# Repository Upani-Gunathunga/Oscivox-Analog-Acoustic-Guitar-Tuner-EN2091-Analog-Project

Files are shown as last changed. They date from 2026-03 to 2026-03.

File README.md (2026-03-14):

# 🎸 Oscivox-Analog-Acoustic-Guitar-Tuner-EN2091-Analog-Project
The Analog Acoustic Guitar Tuner is a fully analog signal-processing system that detects the frequency of a plucked guitar string and visually indicates whether the string is tuned correctly.  Unlike digital tuners, this device performs all signal processing using analog circuits, including filtering, frequency detection, and voltage comparison.

This repository presents the **Analog Acoustic Guitar Tuner** developed by **Team Oscivox** as part of the module:

IN23-S3-EN2091 – Laboratory Practice and Projects
Department of Electronic & Telecommunication Engineering
University of Moratuwa
---

# 📌 Project Overview

The **Analog Acoustic Guitar Tuner** is a **fully analog signal-processing system** that detects the frequency of a plucked guitar string and visually indicates whether the string is tuned correctly.

Unlike digital tuners, this device performs **all signal processing using analog circuits**, including filtering, frequency detection, and voltage comparison.

The system supports standard acoustic guitar tuning:

| String | Note | Frequency |
| --- | ---- | --- |
| 6 | E6 | 82.41 Hz  |
| 5 | A5 | 110 Hz |
| 4 | D4 | 146.83 Hz |
| 3 | G3 | 196 Hz |
| 2 | B2 | 246.94 Hz |
| 1 | E1 | 329.63 Hz |

The device operates using a **9V power supply** and provides tuning feedback using **LED indicators**.

---

# ⚙️ System Working Principle

The overall system processes the acoustic signal through several analog stages.

```
Guitar String Vibration
        ↓
Microphone Input
        ↓
Signal Amplification
        ↓
State Variable Bandpass Filter
        ↓
Schmitt Trigger
        ↓
Frequency-to-Voltage Converter
        ↓
Buffer Stage
        ↓
Comparator Circuit (Potential Dividers)
        ↓
LED Tuning Indicator
```

Each block performs a specific function in converting **sound → frequency → voltage → tuning indication**.

---

# 🔬 System Architecture

## 1️⃣ Microphone Input

🎤 **Purpose**

Convert acoustic vibrations of the guitar string into an electrical signal.

**Key components**

* Condenser microphone
* LM358 operational amplifier
* Variable resistor for gain adjustment

The microphone captures signals typically in the **60–400 Hz frequency range**.

---

## 2️⃣ Amplifier Stage

🔊 **Purpose**

Increase the microphone signal to a usable voltage level.

**Key component**

* **C1845 transistor amplifier**

The amplifier provides approximately:

* **Gain:** 35–40 dB
* **High input impedance (>1 MΩ)**

This stage ensures the signal is strong enough for further processing.

---

## 3️⃣ State Variable Filters

🎚 **Purpose**

Extract the **fundamental frequency** of the selected guitar note while suppressing harmonics and noise.

Six **second-order active band-pass filters** were designed, each corresponding to one guitar string frequency.

State variable filters were chosen because they:

* Provide **sharp frequency selectivity**
* Maintain signal amplitude better than passive filters
* Are suitable for **audio applications**

---

## 4️⃣ Schmitt Trigger

📉 **Purpose**

Convert the filtered analog waveform into a **clean digital square wave**.

**Key component**

* LM393 comparator

This stage removes noise and prepares the signal for frequency measurement.

---

## 5️⃣ Frequency-to-Voltage Converter

🔄 **Purpose**

Convert the signal frequency into a **proportional DC voltage**.

**Key component**

* **LM2917 Frequency-to-Voltage Converter**

This stage transforms frequency information into voltage that can be easily compared.

---

## 6️⃣ Buffer Stage

🧩 **Purpose**

Prevent loading between stages and stabilize the output signal.

**Key component**

* LM358 operational amplifier

---

## 7️⃣ Comparator and Output Indicator

💡 **Purpose**

Determine whether the detected frequency is:

* **Lower than the correct frequency**
* **Higher than the correct frequency**
* **Equal to the correct frequency**
  
Here, potential divider circuit is used to generate reference voltages corresponding to correct tuning frequency of the note as follows.

| Voltage (V) | Frequency (Hz) | Guitar Note |
| --- | --- | --- |
| 1.2 V | 82.4 Hz | E (Low E) |
| 1.6 V | 110 Hz | A |
| 2.1 V | 146.6 Hz | D |
| 2.8 V | 196 Hz | G |
| 3.5 V | 246.9 Hz | B |
| 4.6 V | 329.6 Hz | E (High E)  |

**Key component**

* LM393 comparator

**LED Indications**

| Condition | LED Output |
| --- | --- |
| Frequency too low  | 🟢 Green LED |
| Frequency too high | 🔴 Red LED |
| Correct tuning | 🟢🔴 Both LEDs |

The **output indication of comparator stage were designed as part of my circuit design contribution.**

---

# 🧩 PCB Design

The system was implemented on a **custom PCB designed in Altium**.

### Design considerations

* Efficient component placement
* Reduced noise coupling
* Clear signal routing for analog stages
* Stable power distribution
  
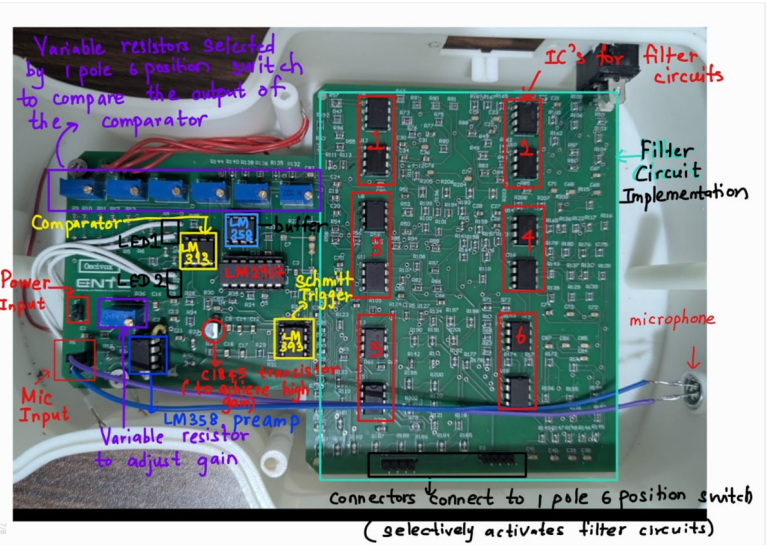
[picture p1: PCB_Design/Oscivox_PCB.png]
Oscivox PCB
  

---

# 🧱 Enclosure Design

The device enclosure was designed using **Autodesk Fusion**.

### Key design goals

* Compact handheld structure
* Easy access to the tuning dial
* Proper positioning of the **microphone near guitar strings**
* Protection of internal circuitry
  
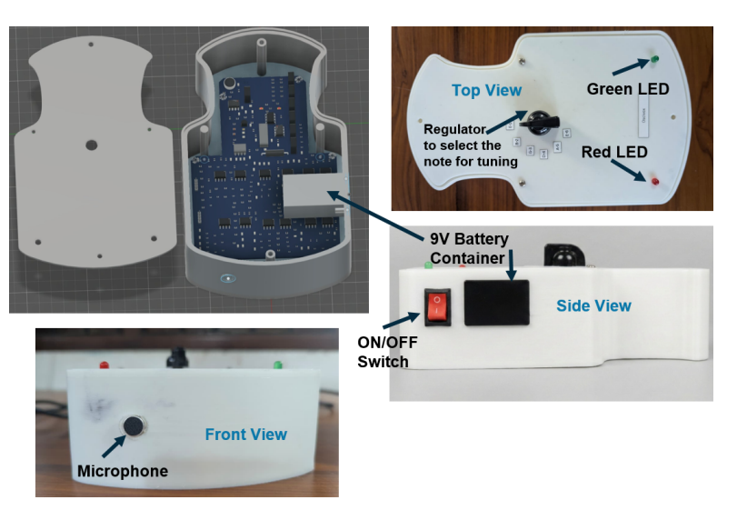
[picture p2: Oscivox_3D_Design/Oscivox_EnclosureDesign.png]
Oscivox Enclosure Design


---

# 🎥 Project Demonstration

A demonstration of the working tuner can be viewed below:

👉 **[Project Demo Video](ADD_VIDEO_LINK_HERE)**

---

# 👥 Team Oscivox

| Name | Index |
| --- | --- |
| Gunathunga U.A. | 230218G |
| Palihena H.H. | 230458P |
| Abeywardhana T.C.W. | 230012U |
| Perera K.W.A.O.V. | 230481E |

---

## 👥 Team Contributions

### **Gunathunga U.A. — 230218G**

* PCB schematic and layout design using **Altium**
* Circuit design for **comparator-based output indication**
* Breadboard testing, PCB debugging, and system assembly

### **Palihena H.H. — 230458P**

* **State Variable Filter** design and LTspice simulations
* Initial passive filter design exploration
* Breadboard implementation and functional testing

### **Abeywardhana T.C.W. — 230012U**

* **Microphone input circuit** and analog amplifier design
* **3D enclosure design** using Fusion
* PCB soldering and hardware assembly

### **Perera K.W.A.O.V. — 230481E**

* Circuit design for **Schmitt Trigger**, **Frequency-to-Voltage Converter**, and **Buffer**
* Design of **reference voltage potential dividers**
* Initial enclosure concept sketch
* Breadboard testing 

---

✔ **Repository Contents**

```
/PCB
/Schematics
/Enclosure
/Simulations
/Datasheet
/Final_Report
README.md
```

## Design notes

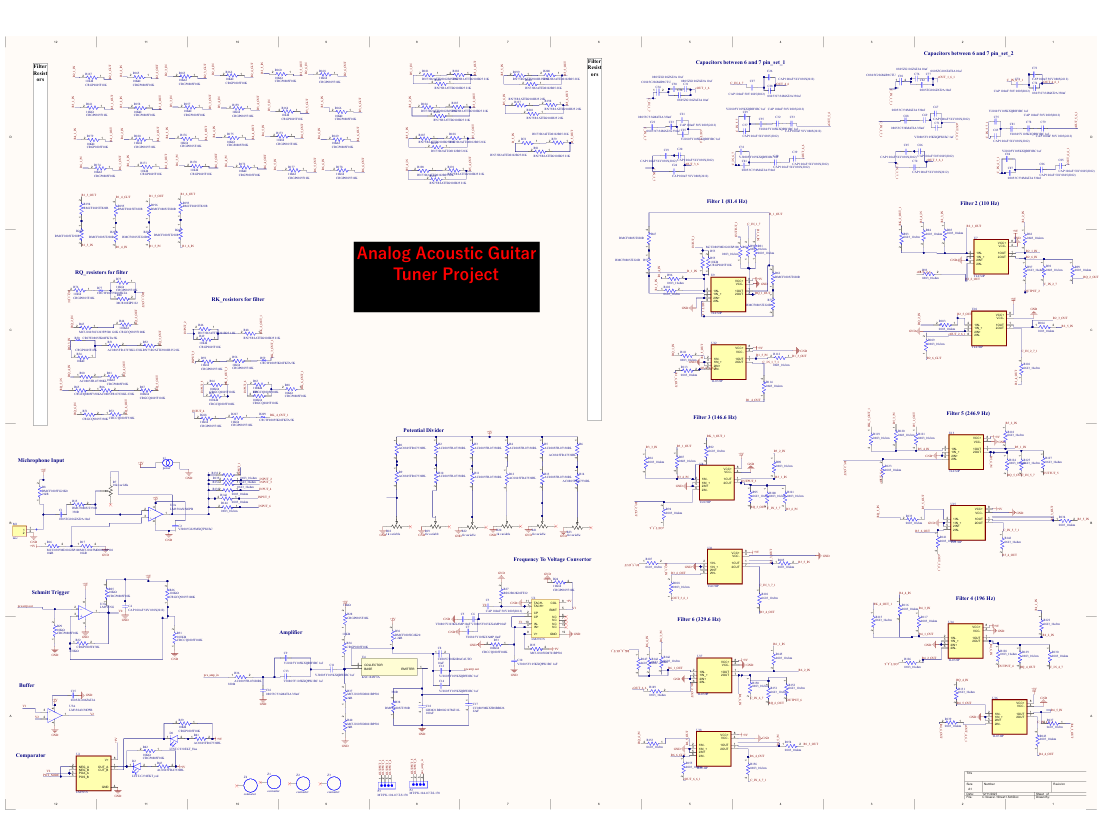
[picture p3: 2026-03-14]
PCB_Design/Oscivox_schematic.png

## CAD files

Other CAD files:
Oscivox_3D_Design/MainBody.f3z

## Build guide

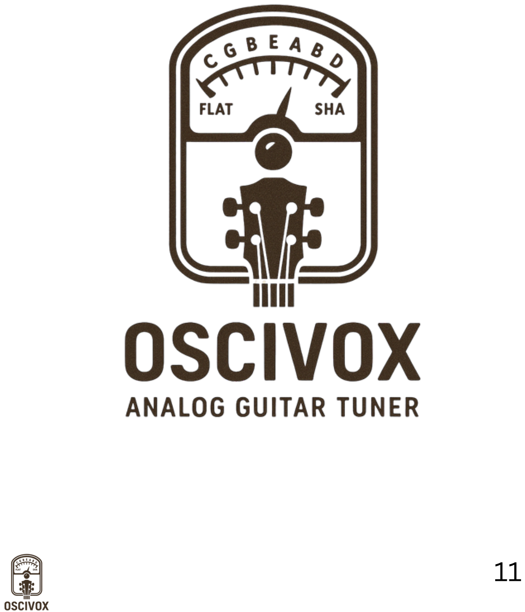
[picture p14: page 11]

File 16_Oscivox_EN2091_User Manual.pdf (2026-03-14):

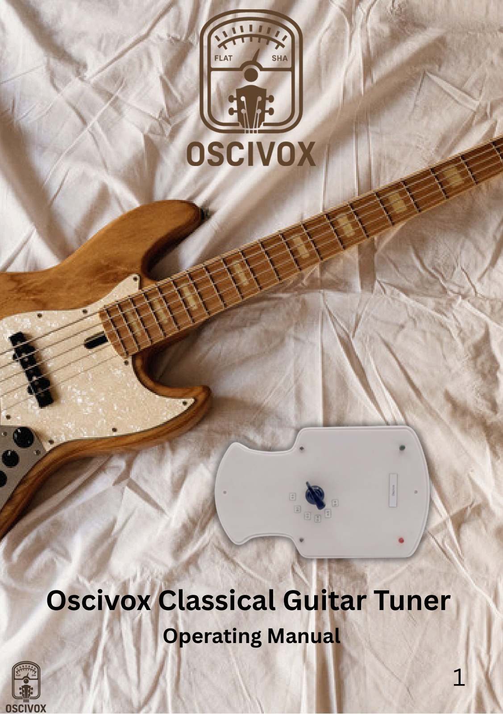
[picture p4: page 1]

# Oscivox Classical Guitar Tuner

## Operating Manual

## Content

## 1.Introduction 2.Safety Information 3.Product Overview 4.What’s in the box 5.Operating Instructions 6.Warranty Information 7.Technical Support and Warranty Claims

# Introduction

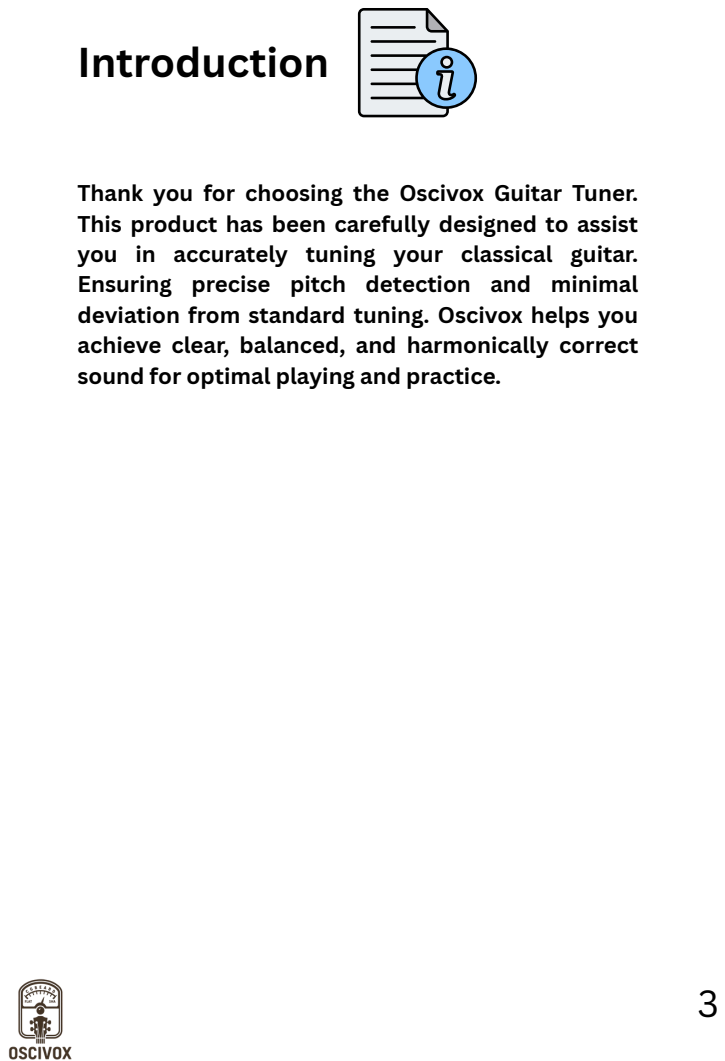
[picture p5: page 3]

Thank you for choosing the Oscivox Guitar Tuner.
This product has been carefully designed to assist
you in accurately tuning your classical guitar.
Ensuring precise pitch detection and minimal
deviation from standard tuning. Oscivox helps you
achieve clear, balanced, and harmonically correct
sound for optimal playing and practice.

Do not leave the device powered on for a long time, as this may damage the internal components.
Do not expose the device to moisture, rain, liquids, or direct heat sources.
Use only a 9 V dry cell battery with a maximum current rating of 300 mA.
Do not open or attempt to modify the device enclosure.
Avoid damaging or obstructing the built-in microphone, as this may affect tuning accuracy.

# Safety Information

# Product Overview

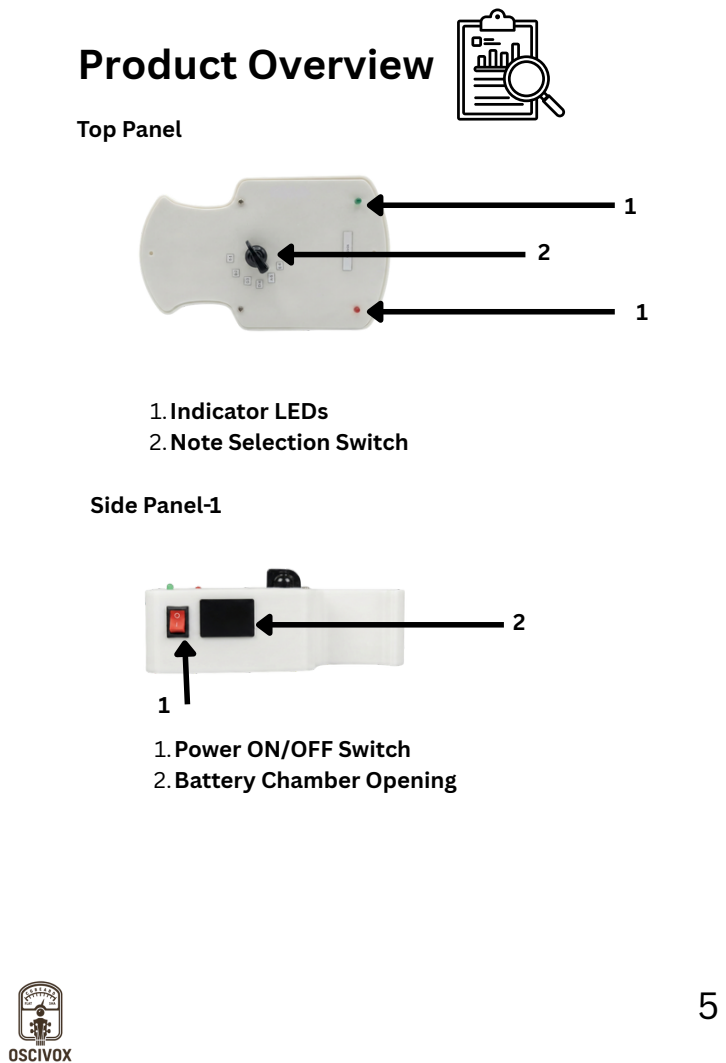
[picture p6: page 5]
Top Panel; Side Panel-1

1.Indicator LEDs
2.Note Selection Switch

1.Power ON/OFF Switch
2.Battery Chamber Opening

# Product Overview

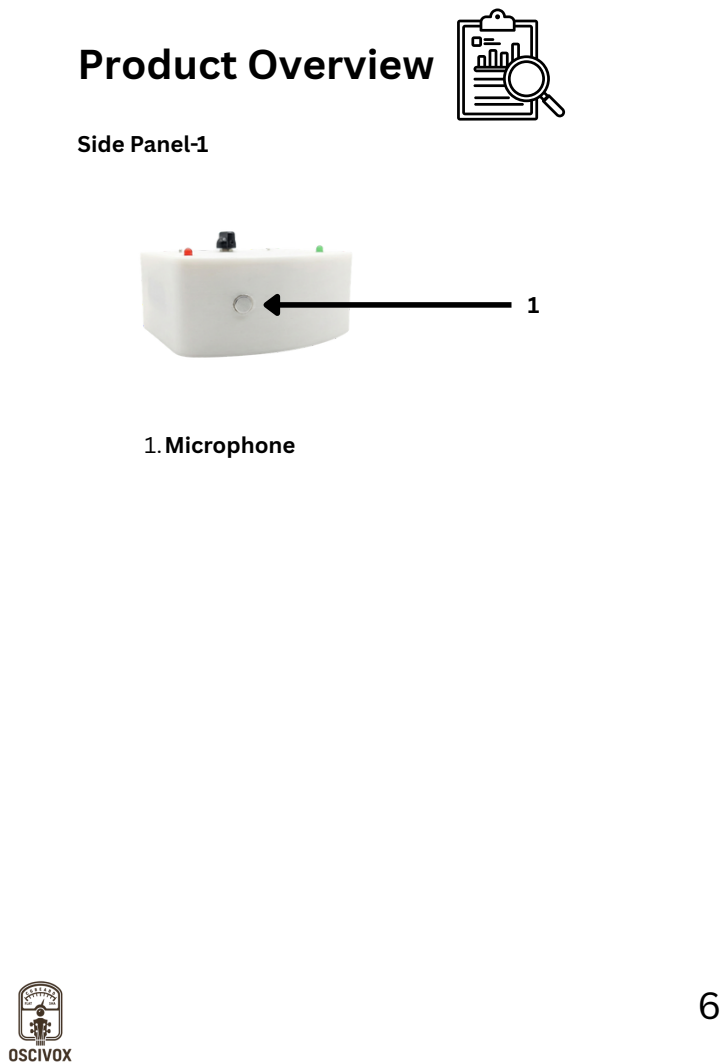
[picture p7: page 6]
Side Panel-1; 1.Microphone

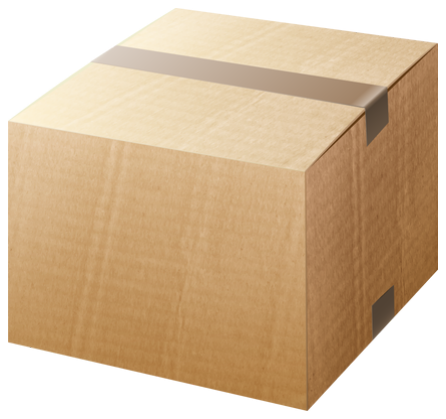
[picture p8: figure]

# What’s in the box

Box Content

Oscivox Guitar tuner unit
9V rechargeable batter
User Manual

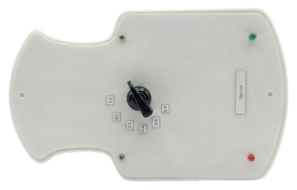
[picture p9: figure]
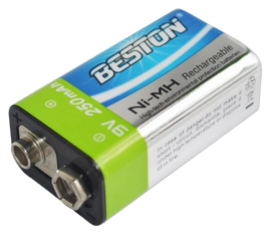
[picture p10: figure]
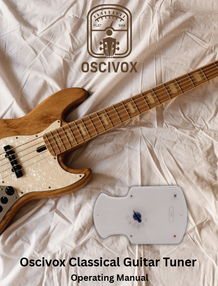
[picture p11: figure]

# Operating Instructions

1.Switch on the Oscivox Guitar Tuner. The green LED will illuminate to indicate that the device is powered on.
2.Allow the device to warm up for 30 to 60 seconds for stable operation.
3.Select the desired note using the rotary switch located on the top panel.
4.Position the Oscivox Guitar Tuner so that the microphone on Side Panel 2 is close to the guitar. 5.Pluck the string to be tuned and observe the indicator LEDs to assess the tuning status.

You will observe

Green LED turned on - String is lower than the expected frequency
Red LED turned on - String is higher than the expected frequency
Both Red and Green LEDs are turned on - Guitar string is perfectly tuned to the expected frequency

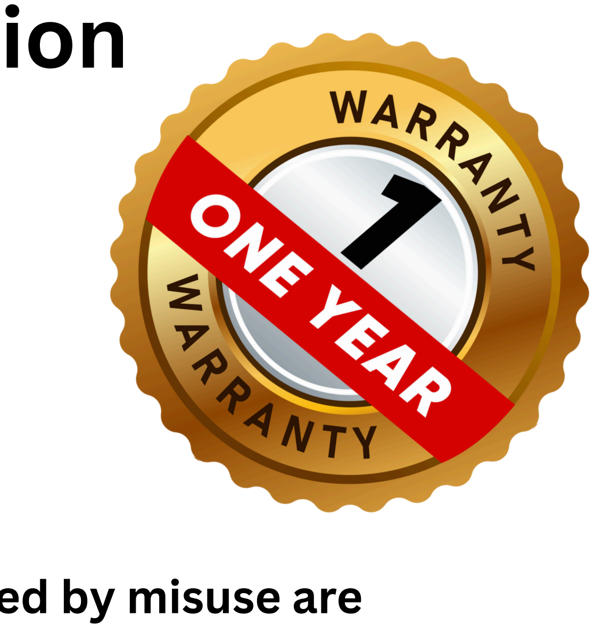
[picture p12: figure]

# Warranty Information

## 1 Year Limited Warranty

Covers

Electrical failures not caused by misuse are covered under warranty.
Manufacturing Defects

NOT Covers

Water damage
Physical Damage

## This warranty shall be void if the seal on the enclosure is

tampered with or broken.

### For technical support, replacements, or warranty-related inquiries, please contact:

Oscivox Engineering

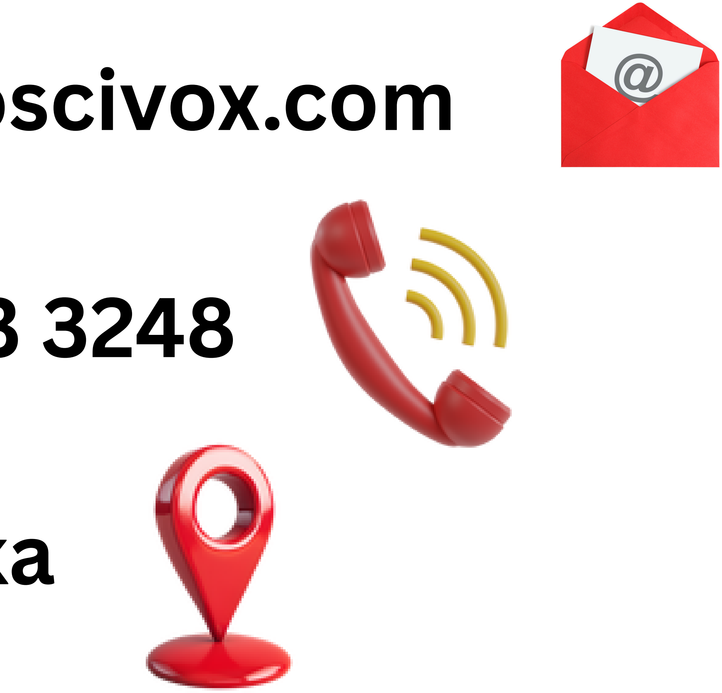
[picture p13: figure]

Email: support@oscivox.com

Phone: +94 74 363 3248

Location: Sri Lanka

# Technical Support and Warranty Claims
